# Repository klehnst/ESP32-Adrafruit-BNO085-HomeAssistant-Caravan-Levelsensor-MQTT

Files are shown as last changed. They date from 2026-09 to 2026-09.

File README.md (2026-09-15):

# WoWa-Level – Wohnwagen/Wohnmobil Neigungssensor

Präziser DIY-Neigungssensor zum Nivellieren von Wohnwagen und Wohnmobilen, mit interaktiver Web-UI, Echtzeit-Wasserwaage und Home-Assistant-Anbindung inkl. Feinjustierung.

<p align="center">
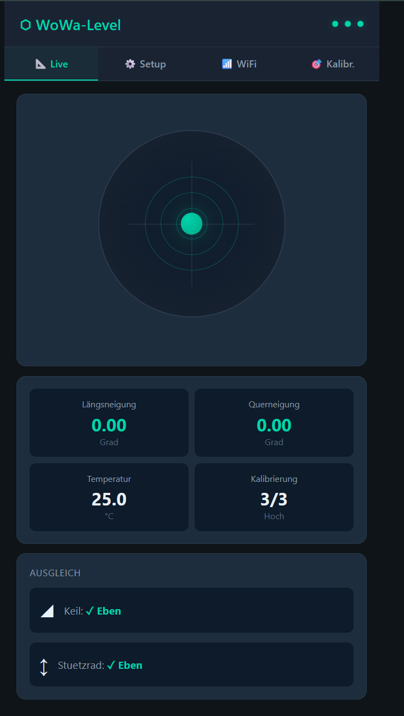
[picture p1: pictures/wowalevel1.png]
Web-UI Hauptseite
  
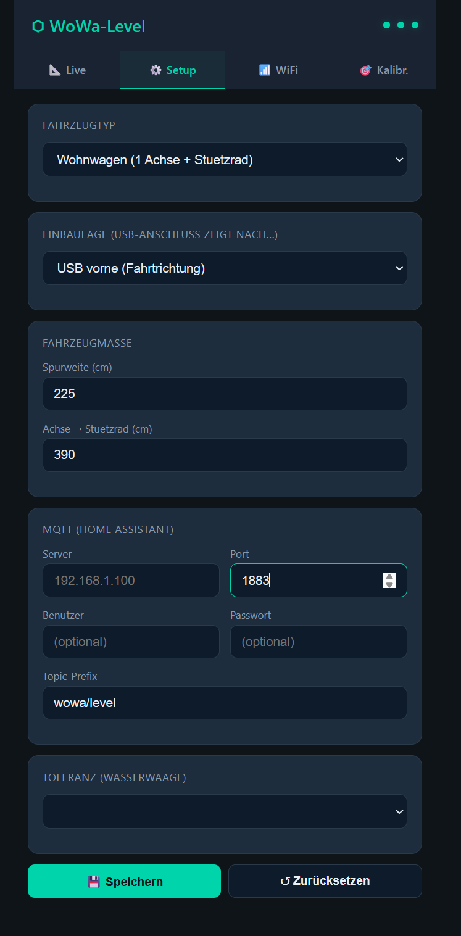
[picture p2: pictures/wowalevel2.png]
Web-UI Einstellungen
  
</p>
<p align="center">
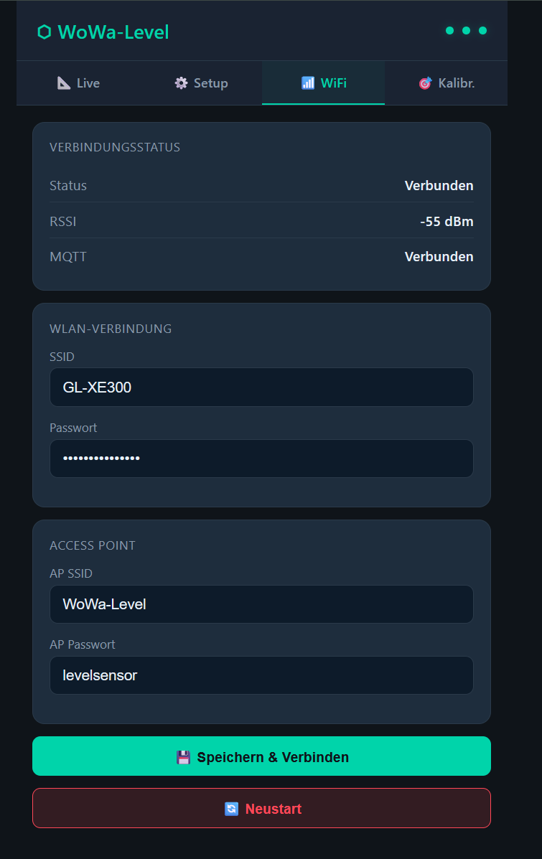
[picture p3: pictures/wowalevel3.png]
Web-UI Kalibrierung
  
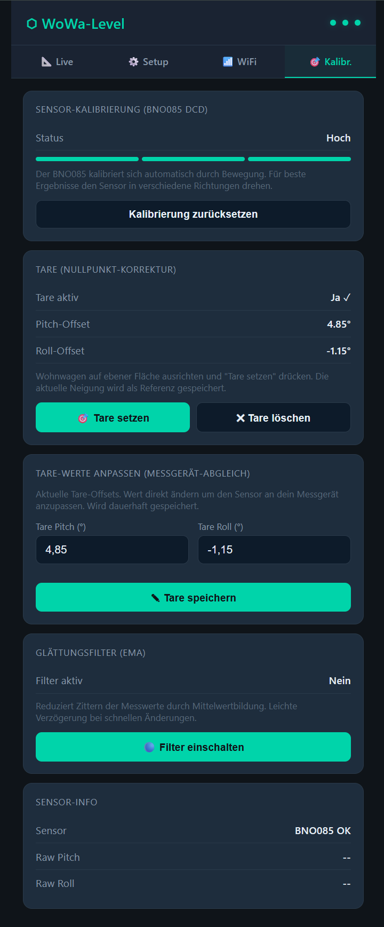
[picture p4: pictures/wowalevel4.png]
Web-UI Live Wasserwaage
  
</p>

---

## Hardware

- **MCU:** ESP32-S3 DevKit
- **IMU:** Adafruit BNO085 9-DoF Breakout (#4754), angebunden über **I2C**
- **Stromversorgung:** USB-C oder 5V/VIN

> **Hinweis:** Das Projekt setzt auf den ESP32-S3. Dieser bietet im Vergleich zu kleineren Controllern eine stabilere Spannungsversorgung unter WiFi-Sende-Peaks und ausreichend Ressourcen für den parallelen Betrieb von WebServer, WebSocket-Streaming und MQTT.

## Pin-Belegung (I2C)

| ESP32-S3 | BNO085 | Funktion |
| --- | --- | --- |
| GPIO1 | SDA | I2C Data |
| GPIO2 | SCL | I2C Clock |
| 3V3 (oder VIN/5V) | VIN | Versorgung |
| GND | GND | Masse |

## 3D-Druck / Gehäuse

Im Ordner [`3D-Print/`](./3D-Print) findest du druckfertige STL-Dateien sowie Vorschaubilder für zwei verschiedene Gehäusevarianten:

- **ESP32-S3 Variante:** `Gehäuse ESP32-S3.stl`, `Deckel ESP32-S3.stl`, `Pfeil ESP32-S3.stl`
- **Standard ESP32-DevKit Variante:** `Gehäuse.stl`, `Deckel.stl`, `Pfeil.stl`

<p align="center">
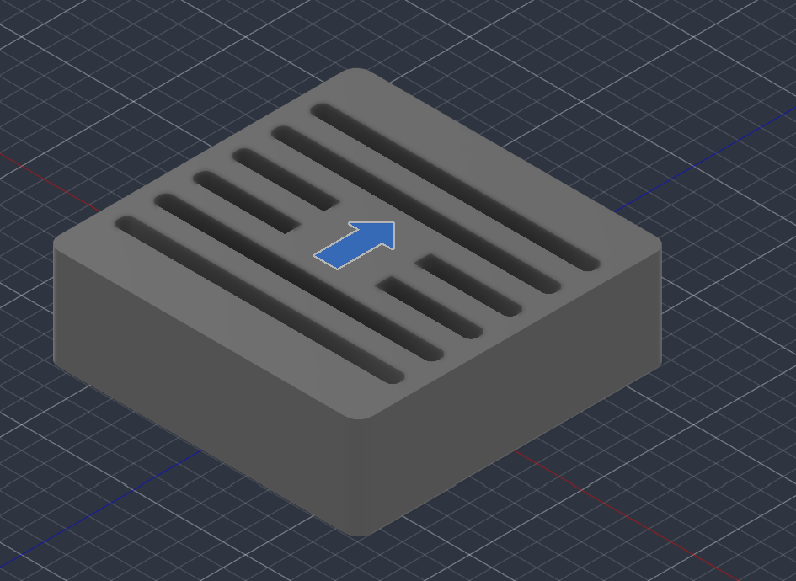
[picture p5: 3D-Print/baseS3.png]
Gehäuse ESP32-S3
  
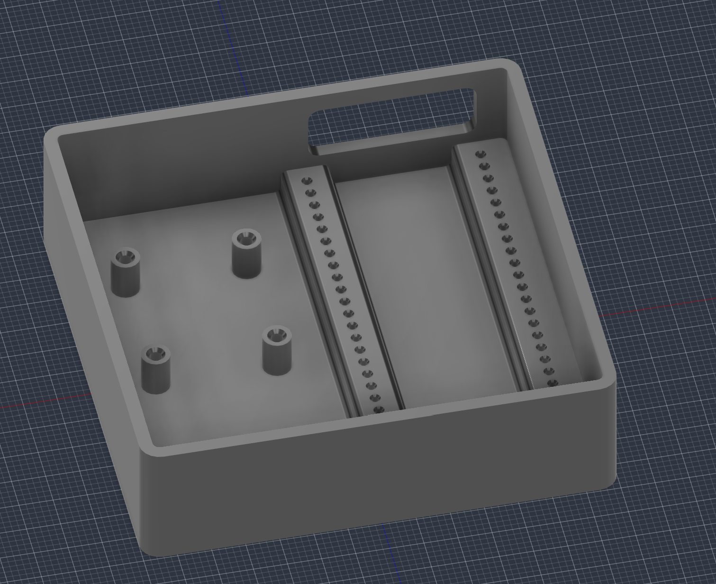
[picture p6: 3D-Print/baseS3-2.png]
Gehäuse ESP32-S3 Ansicht 2
  
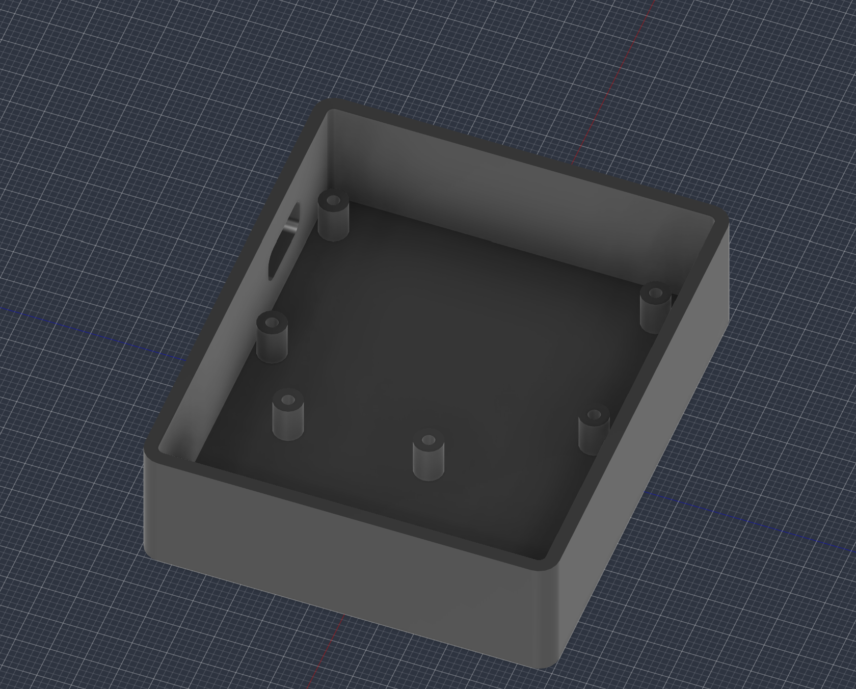
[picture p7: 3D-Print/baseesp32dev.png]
Gehäuse Standard ESP32
  
</p>

## Arduino IDE Setup

### Board

- **Board Manager URL:** `https://raw.githubusercontent.com/espressif/arduino-esp32/gh-pages/package_esp32_index.json`
- **Board:** ESP32S3 Dev Module
- **Flash Size:** 4MB (oder entsprechend dem Modul)
- **Partition Scheme:** Default 4MB with spiffs / LittleFS

### Benötigte Libraries (Library Manager)

1. **SparkFun BNO08x Cortex Based IMU** (by SparkFun)
2. **PubSubClient** (by Nick O'Leary)
3. **ArduinoJson** (by Benoit Blanchon) – Version 7.x
4. **ESPAsyncWebServer** (ESP32Async-Fork)
5. **AsyncTCP** (ESP32Async-Fork)

## Features

- ✅ **BNO085 Accelerometer-Modus:** Driftarm, kein Gyro-Drift, temperaturkompensiert.
- ✅ **Fahrzeugtypen:** Wohnwagen (1 Achse + Stützrad) oder Wohnmobil (2 Achsen, 4 Keile).
- ✅ **Tare-Funktion (Nullpunkt):** Nullpunkt-Kalibrierung mit Speicherung im NVS/Flash.
- ✅ **Tare-Feinjustierung (Fine Offset):** Nachträgliche Korrektur der Pitch- und Roll-Werte (±5.00° in 0.05°-Schritten) über Live-Slider in der Web-UI sowie interaktive `number`-Entitäten in Home Assistant.
- ✅ **Keil-Berechnung:** Errechnet präzise Höhenänderungen in cm für Radkeile und Stützrad (Spurweite / Radstand / Achsabstand konfigurierbar).
- ✅ **Glättungsfilter & Totzone:** Rauschunterdrückung gegen Zittern der Anzeige.
- ✅ **WiFi Manager:** Verlässlicher Connect mit AP-Fallback (`WoWa-Level-AP`) und deaktiviertem WiFi-Power-Save für maximale Stabilität.
- ✅ **MQTT & Home Assistant Auto-Discovery:** Automatische Einbindung aller Sensoren und Bedienelemente inkl. Last-Will-Entdeckung.
- ✅ **Echtzeit Web-UI:** Integrierte responsive Live-Wasserwaage via Websocket, Tabs für Live-Anzeige, Kalibrierung/Feinjustierung und Einstellungen.

## Home Assistant Integration

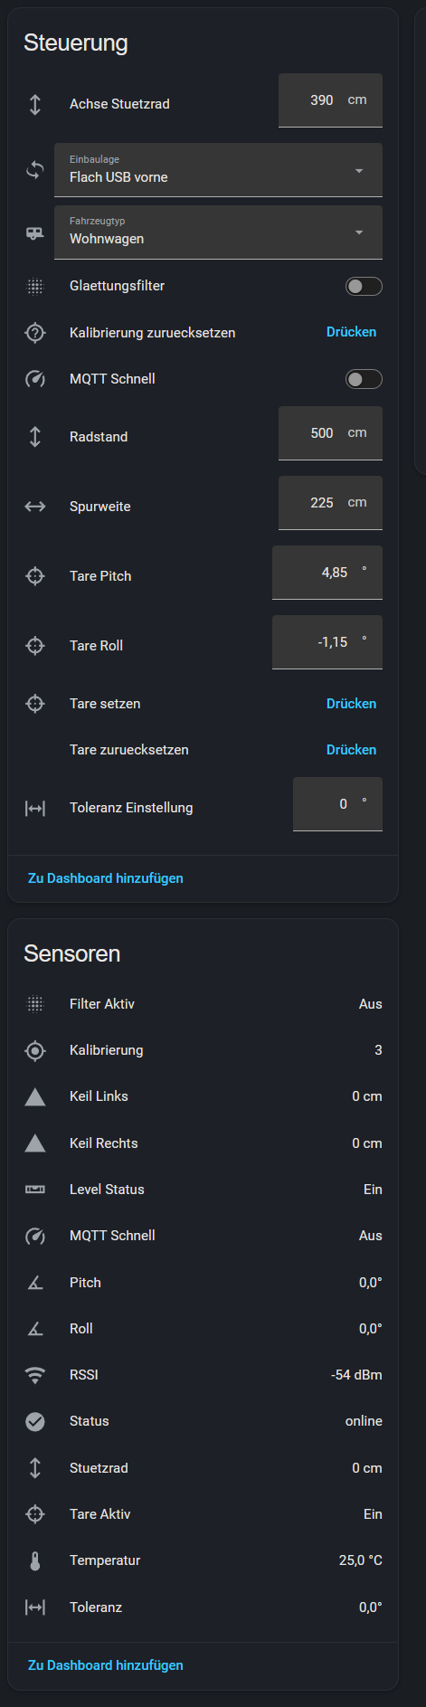
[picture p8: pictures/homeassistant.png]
Home Assistant Dashboard


- **Sensoren:** Pitch, Roll, Keilkorrekturen (Links, Rechts, Stützrad bzw. 4 Keile), Temperatur.
- **Number-Entitäten (Regler):** 
  - `Pitch Feinjustierung` (`-5.0°` bis `+5.0°`, Schrittweite `0.05°`)
  - `Roll Feinjustierung` (`-5.0°` bis `+5.0°`, Schrittweite `0.05°`)
- **Buttons / Switches:** Tare setzen, Tare zurücksetzen, Filter Umschaltung.

> Eine passende Dashboard-Karte befindet sich im Ordner [`WoWa-Level-Card/`](./WoWa-Level-Card).

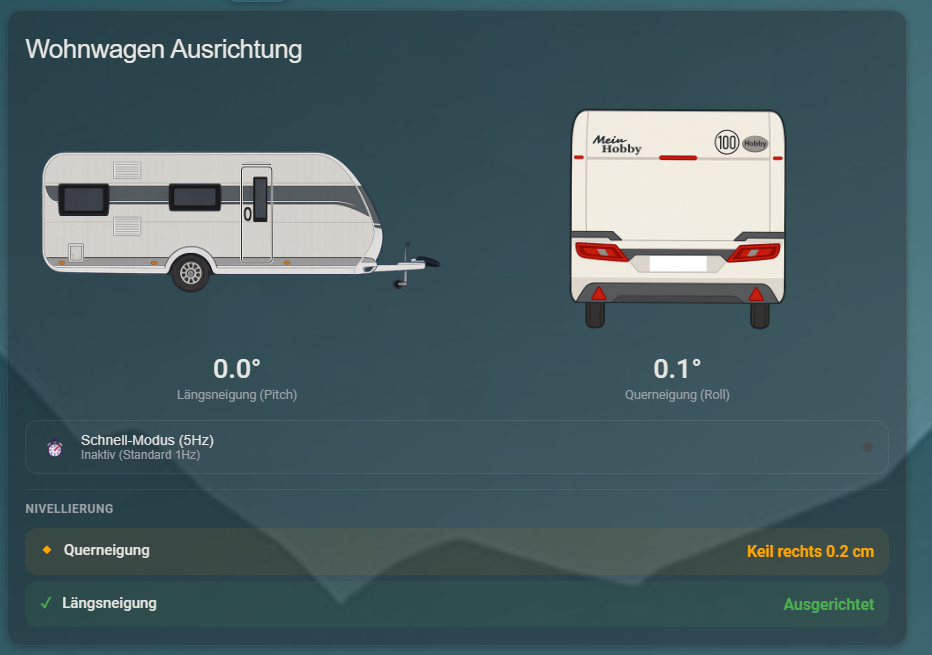
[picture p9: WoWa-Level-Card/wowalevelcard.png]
WoWa Level Card


## MQTT Topics (Prefix: `wowa/level`)

| Topic | Typ | Beschreibung |
| --- | --- | --- |
| `.../pitch` | Sensor | Längsneigung in Grad |
| `.../roll` | Sensor | Querneigung in Grad |
| `.../fine_pitch/state` | State | Aktueller Fine Offset Pitch (Grad) |
| `.../fine_pitch/set` | Command | Fine Offset Pitch setzen (-5.00 bis +5.00) |
| `.../fine_roll/state` | State | Aktueller Fine Offset Roll (Grad) |
| `.../fine_roll/set` | Command | Fine Offset Roll setzen (-5.00 bis +5.00) |
| `.../temperature` | Sensor | Temperatur in °C |
| `.../status` | LWT | `online` / `offline` |
| **Wohnwagen:** | | |
| `.../wedge_left`, `.../wedge_right` | Sensor | Keilhöhe links/rechts (cm) |
| `.../jockey_wheel` | Sensor | Stützrad-Korrektur (cm) |
| **Wohnmobil:** | | |
| `.../wedge_fl`, `.../wedge_fr`, `.../wedge_rl`, `.../wedge_rr` | Sensor | 4 Keile (cm) |

## Erstbenutzung & Kalibrierung

1. **Erstverbindung:** Nach dem ersten Flashen startet der ESP im AP-Modus. Verbinde dich mit dem WLAN `WoWa-Level` (Passwort: `levelsensor`) und öffne `http://192.168.4.1`.
2. **Einbau & Tare:** Richte das Fahrzeug grob aus und drücke in der Web-UI unter **🎯 Kalibr.** den Button **Tare Setzen**.
3. **Feinjustierung:** Überprüfe das Ergebnis mit einer analogen Referenz-Wasserwaage (z. B. auf der Küchenzeile). Gleiche verbleibende Abweichungen komfortabel über die Schieberegler **Pitch Korrektur** und **Roll Korrektur** in der Web-UI oder direkt in Home Assistant ab.
4. **Speichern:** Klicke auf **Feinjustierung Speichern**, um die Offsets dauerhaft im Flash abzulegen.

## Projektstruktur

```text
.
├── 3D-Print/              – STL-Druckdateien und Vorschaubilder (ESP32-S3 & DevKit)
├── data/                  – Dateisystem für LittleFS (enthält index.html)
├── pictures/              – Screenshots für Web-UI und Home Assistant
├── WoWa-Level-Card/       – Lovelace Dashboard Card Ressourcen für Home Assistant
├── config.h               – Systemkonfiguration & Datenstrukturen
├── mqtt_ha.h / .cpp       – MQTT Client & Home Assistant Auto-Discovery
├── sensor.h / .cpp        – BNO085 Ansteuerung, Winkelberechnung & Offsets
├── webserver.h / .cpp     – Webserver, REST-API & WebSocket Broadcast
├── wifi_manager.h / .cpp  – WLAN-Verbindungssteuerung & AP-Fallback
└── wowa_level.ino         – Hauptsketch (Setup & Hauptschleife)

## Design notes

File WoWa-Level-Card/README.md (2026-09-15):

# 🚐 WoWa Level Card v5.3

Eine maßgeschneiderte Lovelace-Karte für **Home Assistant** zur präzisen Ausrichtung und Nivellierung von Wohnwagen und Wohnmobilen.

---

## 🌟 Features

* **Animierte Neigungsanzeige:** Rotations-Visualisierung für Seitenansicht (Längsneigung / Pitch) und Heckansicht (Querneigung / Roll).
* **Nivellier-Anweisungen:**
  * Direkte Höhenanzeige in cm für Keile (links/rechts).
  * Richtungs- und Höhenanweisungen für das Stützrad (hoch/runter in cm).
* **Schnell-Modus / Boost-Modus:**
  * Integrierter Button zum Schalten einer höheren Sensor-Abtastrate (z. B. 5 Hz via ESPHome).
  * Auto-Reset-Timer schaltet den Boost-Modus nach Ablauf der eingestellten Zeit automatisch wieder ab.
* **Erweiterte Konfiguration:**
  * Achsen-Invertierung und Achsen-Tausch (Pitch / Roll).
  * Separates Invertieren der Text-Anweisungen (falls Keilzuordnungen gespiegelt sind).
  * Flacker-Schutz mit Hysterese-Logik an den Toleranzgrenzen.
  * Dauerhafte Textanzeige aller Achsen oder dynamische Aktionsanweisung.
* **Visueller Editor:** Vollständig integrierter GUI-Editor zur bequemen Konfiguration im Dashboard.

WoWa Level Card

---

## 📦 Installation

### Manuelle Installation

1. Erstelle auf deinem Home Assistant Server folgenden Ordner (falls nicht vorhanden):
   ```bash
   /config/www/wowa-level-card/
   ```
2. Speichere die Datei `wowa-level-card.js` in diesem Ordner ab.
3. Lege deine Bilddateien im Unterordner `img` ab:
   ```bash
   /config/www/wowa-level-card/img/seitenansichtkleiner.png
   /config/www/wowa-level-card/img/heckansicht.png
   ```
4. Registriere die Karte als Ressource in Home Assistant:
   * Gehe zu **Einstellungen** ➔ **Dashboards** ➔ oben rechts auf das **3-Punkte-Menü** ➔ **Ressourcen**.
   * Klicke auf **Ressource hinzufügen**.
   * **URL:** `/local/wowa-level-card/wowa-level-card.js?v=5.3`
   * **Typ:** `JavaScript-Modul`

---

## ⚙️ Konfiguration

Die Karte kann direkt über den **visuellen Dashboard-Editor** oder per **YAML** konfiguriert werden.

### YAML-Beispiel

```yaml
type: custom:wowa-level-card
name: Wohnwagen Ausrichtung
entity_roll: sensor.wowa_roll
entity_pitch: sensor.wowa_pitch
entity_level_ok: binary_sensor.wowa_ausgerichtet
entity_wedge_left: sensor.wowa_keil_links
entity_wedge_right: sensor.wowa_keil_rechts
entity_support: sensor.wowa_stutzrad
entity_boost: switch.wowa_sensor_boost
boost_duration: 60
tolerance: 0.5
visual_factor: 3
anti_flicker: true
always_show_text: false
swap_pitch_roll: false
invert_roll: true
invert_pitch: false
invert_roll_text: false
invert_pitch_text: false
image_side: /local/wowa-level-card/img/seitenansichtkleiner.png
image_rear: /local/wowa-level-card/img/heckansicht.png
```

---

## 📋 Optionen

| Parameter | Typ | Standard | Beschreibung |
| :--- | :--- | :--- | :--- |
| `name` | String | `Wohnwagen Ausrichtung` | Titel der Karte im Dashboard |
| `entity_roll` | String | *erforderlich* | Sensor für Querneigung (Roll) in Grad |
| `entity_pitch` | String | *erforderlich* | Sensor für Längsneigung (Pitch) in Grad |
| `entity_level_ok` | String | *optional* | Binary Sensor (`on`/`off`), der die korrekte Ausrichtung meldet |
| `entity_wedge_left` | String | *optional* | Sensor für die Keilhöhe links in cm |
| `entity_wedge_right` | String | *optional* | Sensor für die Keilhöhe rechts in cm |
| `entity_support` | String | *optional* | Sensor für Höhenkorrektur am Stützrad in cm |
| `entity_boost` | String | *optional* | Switch-Entity zur Aktivierung des Fast-Update-Modus |
| `boost_duration` | Zahl | `60` | Auto-Off-Timer für den Boost-Modus in Sekunden |
| `tolerance` | Zahl | `0.5` | Toleranzwert in Grad für die Grün-Bewertung |
| `visual_factor` | Zahl | `3` | Multiplikator für die grafische Neigung |
| `anti_flicker` | Boolean | `true` | Aktiviert die Hysterese gegen Flackern an Grenzwerten |
| `always_show_text` | Boolean | `false` | Zeigt beide Achsen dauerhaft im Textbereich an |
| `swap_pitch_roll` | Boolean | `false` | Vertauscht Pitch- und Roll-Eingänge |
| `invert_roll` | Boolean | `true` | Invertiert die Drehung des Heckbildes |
| `invert_pitch` | Boolean | `false` | Invertiert die Drehung des Seitenbildes |
| `invert_roll_text` | Boolean | `false` | Invertiert Richtungsanweisungen & Keil-Zuordnung links/rechts |
| `invert_pitch_text` | Boolean | `false` | Invertiert Richtungsanweisungen für das Stützrad (hoch/runter) |
| `image_side` | String | `/local/...` | Pfad zum Bild der Seitenansicht |
| `image_rear` | String | `/local/...` | Pfad zum Bild der Heckansicht |

---

## 🖼️ Bild-Assets

Für eine optimale Darstellung sollten die Bilder als **PNG mit transparentem Hintergrund** vorliegen:
* **Seitenansicht (`image_side`):** Seitenprofil des Wohnwagens (Deichsel vorzugsweise nach links).
* **Heckansicht (`image_rear`):** Ansicht des Wohnwagens von hinten.

---

## 📄 Lizenz

MIT License – Frei nutzbar und anpassbar.

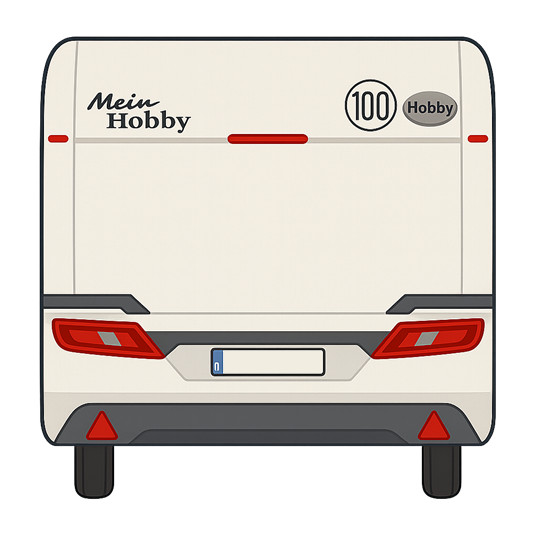
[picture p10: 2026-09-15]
WoWa-Level-Card/heckansicht.png

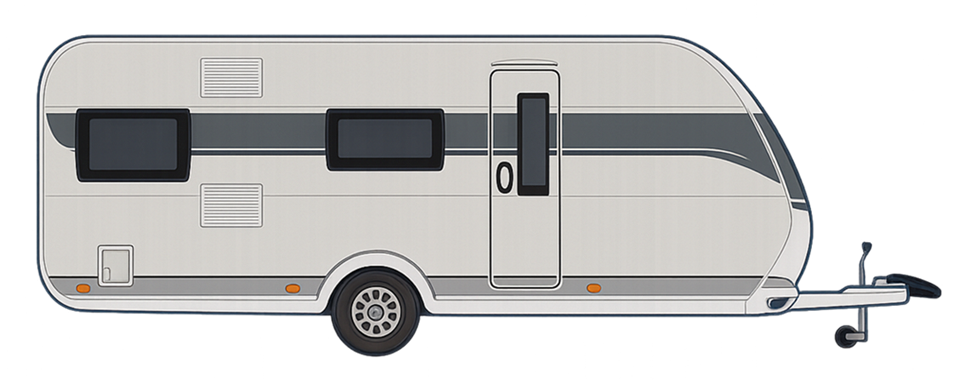
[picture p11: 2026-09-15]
WoWa-Level-Card/seitenansichtkleiner.png

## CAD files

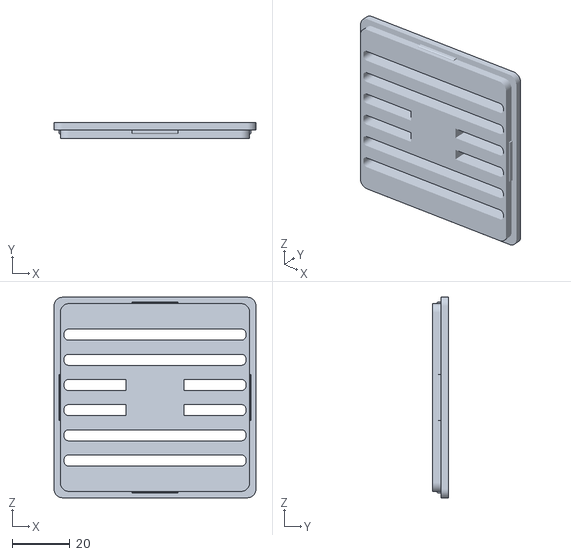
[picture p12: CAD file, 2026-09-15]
3D-Print/Deckel ESP32-S3.stl
70.0 x 5.50 x 69.5

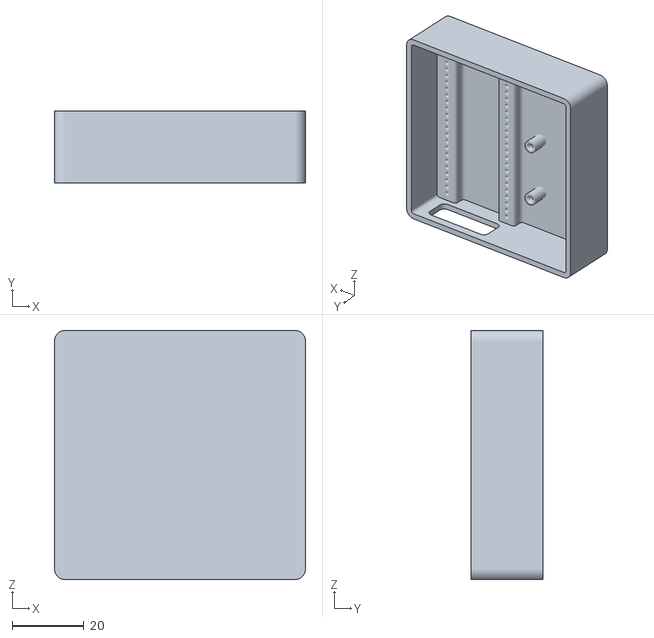
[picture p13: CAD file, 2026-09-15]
3D-Print/Gehäuse ESP32-S3.stl
70.0 x 20.0 x 69.5

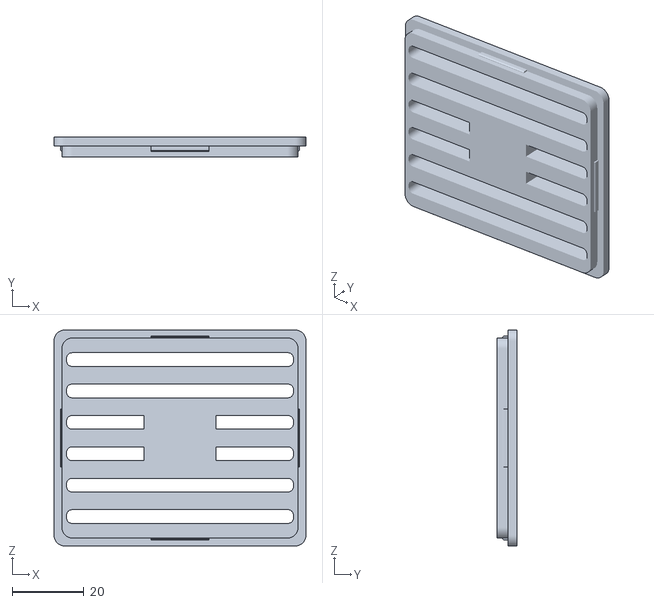
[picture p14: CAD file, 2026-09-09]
3D-Print/Deckel.stl
70.0 x 5.50 x 60.0

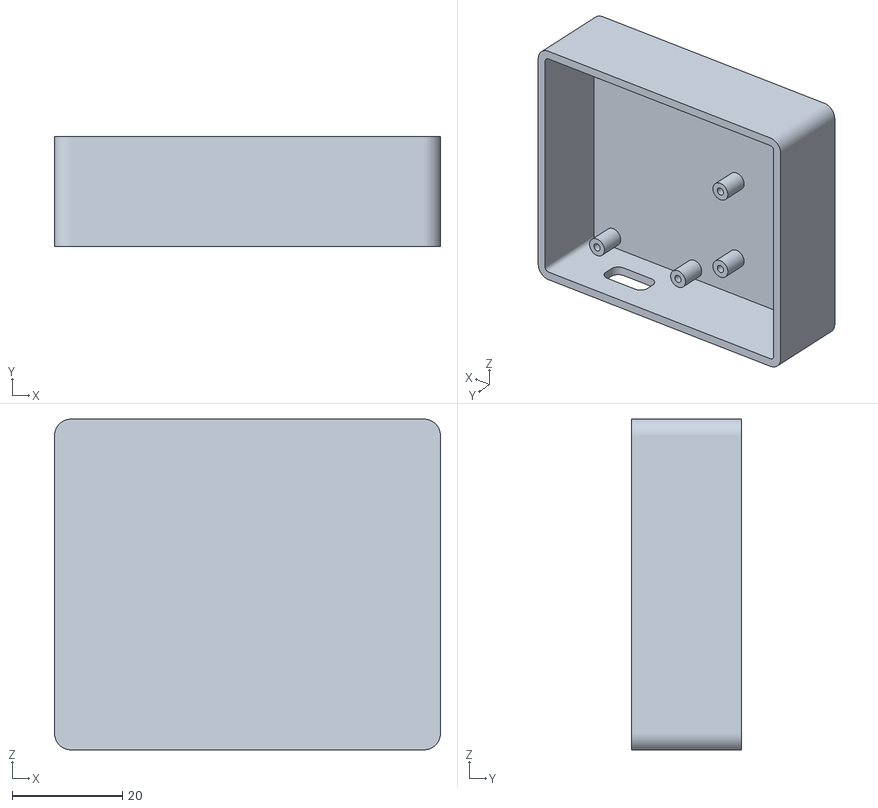
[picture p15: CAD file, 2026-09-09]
3D-Print/Gehäuse.stl
70.0 x 20.0 x 60.0

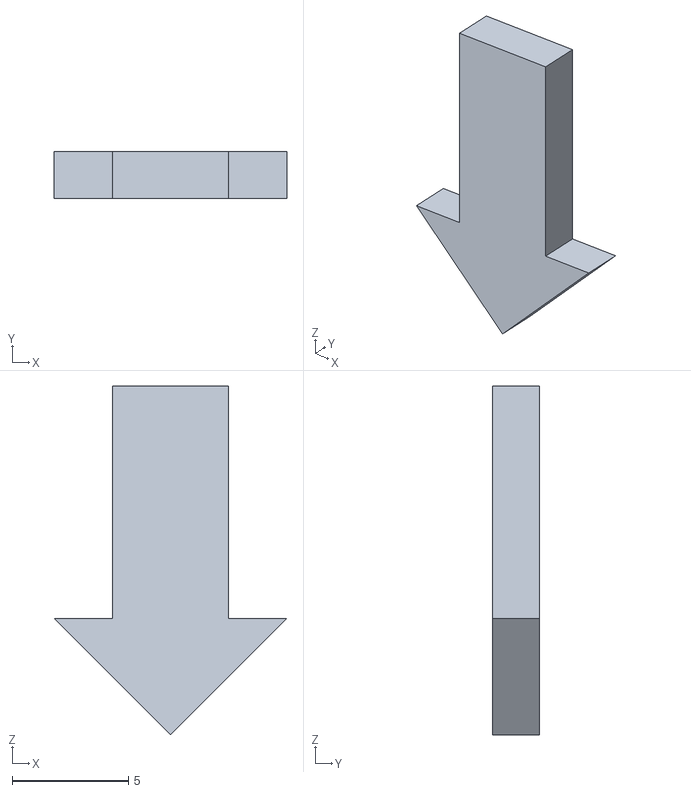
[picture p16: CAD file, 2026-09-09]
3D-Print/Pfeil ESP32-S3.stl
10.0 x 2.00 x 15.0

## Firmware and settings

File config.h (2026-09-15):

#ifndef CONFIG_H
#define CONFIG_H

#include <Arduino.h>

// ============================================================
// PIN DEFINITIONS - ESP32 S3 + BNO085 I2C
#define PIN_I2C_SDA   1
#define PIN_I2C_SCL   2
#define BNO08X_I2C_ADDR 0x4A  // Default I2C address
// ============================================================

// ============================================================
// DEFAULT CONFIGURATION VALUES
// ============================================================
#define DEFAULT_AP_SSID       "WoWa-Level"
#define DEFAULT_AP_PASSWORD   "levelsensor"
#define DEFAULT_AP_IP         "192.168.4.1"
#define WIFI_CONNECT_TIMEOUT  60000  // 60 seconds

#define DEFAULT_MQTT_SERVER   "192.168.1.100"
#define DEFAULT_MQTT_PORT     1883
#define DEFAULT_MQTT_USER     ""
#define DEFAULT_MQTT_PASS     ""
#define DEFAULT_MQTT_PREFIX   "wowa/level"

#define DEFAULT_TRACK_WIDTH   225.0f   // cm - Spurweite
#define DEFAULT_WHEELBASE     500.0f   // cm - Radstand (Wohnmobil)
#define DEFAULT_AXLE_JOCKEY   390.0f   // cm - Achse zu Stuetzrad (Wohnwagen)

#define DEFAULT_TOLERANCE     0.5f     // degrees

#define SENSOR_UPDATE_MS      100      // 10 Hz sensor read
#define MQTT_FAST_MS          200      // 5 Hz (Einrichten)
#define MQTT_SLOW_MS          2000     // 0.5 Hz (Dauerbetrieb)
#define WS_UPDATE_MS          200      // 5 Hz WebSocket

#define CONFIG_FILE           "/config.json"
#define OTA_HOSTNAME          "wowa-level"

// ============================================================
// VEHICLE TYPE
// ============================================================
enum VehicleType {
    VEHICLE_CARAVAN   = 0,  // Wohnwagen (1 Achse + Stuetzrad)
    VEHICLE_MOTORHOME = 1   // Wohnmobil (2 Achsen)
};

// ============================================================
// MOUNTING ORIENTATION
// Flach: Sensor liegt horizontal, USB zeigt in angegebene Richtung
// Wand:  Sensor haengt vertikal an der Wand, USB zeigt nach UNTEN
//        "Wand vorne" = an der Vorderwand montiert
// ============================================================
enum MountOrientation {
    // Flachmontage
    MOUNT_USB_FRONT = 0,   // Flach, USB zeigt nach vorne (Fahrtrichtung)
    MOUNT_USB_BACK  = 1,   // Flach, USB zeigt nach hinten
    MOUNT_USB_LEFT  = 2,   // Flach, USB zeigt nach links
    MOUNT_USB_RIGHT = 3,   // Flach, USB zeigt nach rechts
    // Wandmontage (USB zeigt nach unten)
    MOUNT_WALL_FRONT = 4,  // An Vorderwand (Platine zeigt nach hinten)
    MOUNT_WALL_BACK  = 5,  // An Rueckwand (Platine zeigt nach vorne)
    MOUNT_WALL_LEFT  = 6,  // An linker Wand (Platine zeigt nach rechts)
    MOUNT_WALL_RIGHT = 7   // An rechter Wand (Platine zeigt nach links)
};

// ============================================================
// CONFIGURATION STRUCT
// ============================================================
struct AppConfig {
    // WiFi Station
    char wifi_ssid[64];
    char wifi_pass[64];
    
    // WiFi AP
    char ap_ssid[32];
    char ap_pass[32];
    
    // MQTT
    char mqtt_server[64];
    uint16_t mqtt_port;
    char mqtt_user[32];
    char mqtt_pass[32];
    char mqtt_prefix[32];
    
    // Sensor / Vehicle
    VehicleType vehicle_type;
    MountOrientation mount;
    float track_width;     // Spurweite in cm
    float wheelbase;       // Radstand in cm (Wohnmobil)
    float axle_to_jockey;  // Achse zu Stuetzrad (Wohnwagen) in cm
    float tolerance;       // Toleranz in Grad
    
    // Tare offsets
    float tare_pitch;
    float tare_roll;
    bool tare_active;
    bool filter_active;    // Glaettungsfilter ein/aus
    bool mqtt_fast;        // true=5Hz, false=0.5Hz
};

// ============================================================
// SENSOR DATA STRUCT
// ============================================================
struct SensorData {
    float raw_pitch;
    float raw_roll;
    float pitch;           // nach Tare und Einbaulage
    float roll;            // nach Tare und Einbaulage
    float temperature;
    float wedge_left;      // Keilhoehe links in cm
    float wedge_right;     // Keilhoehe rechts in cm
    float jockey_wheel;    // Stuetzrad-Korrektur in cm
    // Wohnmobil (motorhome)
    float wedge_fl;        // Keil vorne links
    float wedge_fr;        // Keil vorne rechts
    float wedge_rl;        // Keil hinten links
    float wedge_rr;        // Keil hinten rechts
    // Raw gravity vector (for debugging)
    float gx, gy, gz;
    uint8_t cal_status;    // Kalibrierungsstatus 0-3
    bool is_level;         // true wenn innerhalb Toleranz
    bool sensor_ok;
    int rssi;
};

// ============================================================
// GLOBAL EXTERNS
// ============================================================
extern AppConfig config;
extern SensorData sensorData;

#endif // CONFIG_H

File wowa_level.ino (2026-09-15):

/*
 * WoWa-Level - Wohnwagen Neigungssensor
 * ======================================
 * Hardware: ESP32-C3 Super Mini + Adafruit BNO085 (I2C)
 * 
 * Pin Belegung:
 *   GPIO4  -> SDA (I2C)
 *   GPIO10 -> SCL (I2C)
 */

#include <Arduino.h>
#include <ArduinoOTA.h>
#include <WiFi.h>

#include "config.h"
#include "wifi_manager.h"
#include "sensor.h"
#include "mqtt_ha.h"
#include "webserver.h"

AppConfig config;
SensorData sensorData;

static unsigned long lastStatusPrint = 0;
static bool sensorStarted = false;

void setupOTA() {
    ArduinoOTA.setHostname(OTA_HOSTNAME);
    ArduinoOTA.setPassword("wowa2024");
    
    ArduinoOTA.onStart([]() {
        String type = (ArduinoOTA.getCommand() == U_FLASH) ? "sketch" : "filesystem";
        Serial.println("[OTA] Start updating " + type);
    });
    ArduinoOTA.onEnd([]() {
        Serial.println("\n[OTA] Update complete!");
    });
    ArduinoOTA.onProgress([](unsigned int progress, unsigned int total) {
        Serial.printf("[OTA] Progress: %u%%\r", (progress / (total / 100)));
    });
    ArduinoOTA.onError([](ota_error_t error) {
        Serial.printf("[OTA] Error[%u]\n", error);
    });
    
    ArduinoOTA.begin();
    Serial.println("[OTA] Ready");
}

void setup() {
    Serial.begin(115200);
    delay(1000);
    
    Serial.println();
    Serial.println("========================================");
    Serial.println("  WoWa-Level v1.0 (ESP32-C3 + BNO085)");
    Serial.println("========================================");
    Serial.println();
    
    memset(&sensorData, 0, sizeof(SensorData));
    
    // Phase 1: Config
    webserverInit();
    
    // Phase 2: WiFi (blockierend)
    wifiManagerInit();
    
    // Phase 3: Webserver
    webserverStart();
    
    // Phase 4: OTA + MQTT
    setupOTA();
    mqttInit();
    
    // Phase 5: Sensor wird NICHT hier gestartet!
    // Startet erst im loop() nach 3 Sekunden stabilem Betrieb
    Serial.println("[MAIN] Sensor init deferred to loop()");
    
    Serial.printf("[MAIN] Setup done! Heap: %d\n", ESP.getFreeHeap());
}

void loop() {
    wifiManagerLoop();
    ArduinoOTA.handle();
    
    // Deferred sensor init — erst nach 3s im Loop
    if (!sensorStarted && millis() > 5000) {
        sensorStarted = true;
        Serial.println("[MAIN] Deferred sensor init starting...");
        if (!sensorInit()) {
            Serial.println("[MAIN] WARNING: Sensor init failed");
        } else {
            Serial.println("[MAIN] Sensor OK!");
        }
    }
    
    if (sensorStarted) {
        sensorLoop();
    }
    
    mqttLoop();
    webserverLoop();
    
    // Serial commands
    if (Serial.available()) {
        String cmd = Serial.readStringUntil('\n');
        cmd.trim();
        if (cmd == "cal") {
            Serial.println("[CMD] Calibration reset...");
            sensorResetCalibration();
        } else if (cmd == "tare") {
            Serial.println("[CMD] Tare set");
            sensorSetTare();
        } else if (cmd == "notare") {
            Serial.println("[CMD] Tare reset");
            sensorResetTare();
        } else if (cmd == "grav") {
            Serial.printf("[GRAV] gx=%.3f gy=%.3f gz=%.3f\n",
                sensorData.gx, sensorData.gy, sensorData.gz);
            Serial.printf("[GRAV] Mount=%d → P=%.2f R=%.2f\n",
                (int)config.mount, sensorData.pitch, sensorData.roll);
        } else if (cmd == "filter") {
            config.filter_active = !config.filter_active;
            Serial.printf("[CMD] Filter: %s\n", config.filter_active ? "ON" : "OFF");
        } else if (cmd == "fast") {
            config.mqtt_fast = !config.mqtt_fast;
            Serial.printf("[CMD] MQTT: %s\n", config.mqtt_fast ? "5 Hz" : "0.5 Hz");
        } else if (cmd == "help") {
            Serial.println("[CMD] Commands: cal, tare, notare, grav, filter, fast, help");
        }
    }
    
    if (millis() - lastStatusPrint > 10000) {
        lastStatusPrint = millis();
        Serial.printf("[STATUS] P:%.2f R:%.2f Cal:%d WiFi:%s MQTT:%s Heap:%d\n",
            sensorData.pitch, sensorData.roll, sensorData.cal_status,
            getWiFiStateString().c_str(),
            mqttIsConnected() ? "OK" : "---",
            ESP.getFreeHeap());
    }
    
    delay(5);
    yield();
}

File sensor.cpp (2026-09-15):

#include "sensor.h"
#include <Wire.h>
#include <SparkFun_BNO08x_Arduino_Library.h>
#include "webserver.h"   // fuer saveConfig()

static BNO08x imu;
static unsigned long lastSensorRead = 0;

// Totzone fuer Anzeige
#define DEADBAND 0.1f

// ============================================================
// Einbaulage (Remap der Roh-Euler-Winkel je nach Montage)
// ============================================================
static void applyMountingOrientation(float rawPitch, float rawRoll, float* outPitch, float* outRoll) {
    switch (config.mount) {
        // --- Flach auf dem Boden ---
        case MOUNT_USB_FRONT:
            *outPitch = rawPitch;
            *outRoll  = rawRoll;
            break;
        case MOUNT_USB_BACK:
            *outPitch = -rawPitch;
            *outRoll  = -rawRoll;
            break;
        case MOUNT_USB_LEFT:
            *outPitch = rawRoll;
            *outRoll  = -rawPitch;
            break;
        case MOUNT_USB_RIGHT:
            *outPitch = -rawRoll;
            *outRoll  = rawPitch;
            break;

        // --- Wandmontage ---
        case MOUNT_WALL_FRONT:
            *outPitch = rawRoll;
            *outRoll  = rawPitch;
            break;
        case MOUNT_WALL_BACK:
            *outPitch = -rawRoll;
            *outRoll  = -rawPitch;
            break;
        case MOUNT_WALL_LEFT:
            *outPitch = rawPitch;
            *outRoll  = -rawRoll;
            break;
        case MOUNT_WALL_RIGHT:
            *outPitch = -rawPitch;
            *outRoll  = rawRoll;
            break;

        default:
            *outPitch = rawPitch;
            *outRoll  = rawRoll;
            break;
    }
}

// ============================================================
// Keil-Berechnung
// ============================================================
static void calculateWedges() {
    float rollRad = sensorData.roll * DEG_TO_RAD;
    float pitchRad = sensorData.pitch * DEG_TO_RAD;
    
    if (config.vehicle_type == VEHICLE_CARAVAN) {
        float lateralOffset = tanf(rollRad) * config.track_width / 2.0f;
        if (lateralOffset > 0) {
            sensorData.wedge_right = lateralOffset;
            sensorData.wedge_left = 0.0f;
        } else {
            sensorData.wedge_left = -lateralOffset;
            sensorData.wedge_right = 0.0f;
        }
        sensorData.jockey_wheel = tanf(pitchRad) * config.axle_to_jockey;
        sensorData.wedge_fl = sensorData.wedge_fr = 0.0f;
        sensorData.wedge_rl = sensorData.wedge_rr = 0.0f;
    } else {
        float latOff = tanf(rollRad) * config.track_width / 2.0f;
        float lonOff = tanf(pitchRad) * config.wheelbase / 2.0f;
        sensorData.wedge_fl = fmaxf(0.0f, -latOff - lonOff);
        sensorData.wedge_fr = fmaxf(0.0f,  latOff - lonOff);
        sensorData.wedge_rl = fmaxf(0.0f, -latOff + lonOff);
        sensorData.wedge_rr = fmaxf(0.0f,  latOff + lonOff);
        sensorData.wedge_left = sensorData.wedge_right = 0.0f;
        sensorData.jockey_wheel = 0.0f;
    }
}

// ============================================================
// Sensor Init — Game Rotation Vector (Accel + Gyro Fusion)
// ============================================================
bool sensorInit() {
    Serial.println("[Sensor] Initializing I2C...");
    Wire.begin(PIN_I2C_SDA, PIN_I2C_SCL);
    Serial.printf("[Sensor] Pins: SDA=%d SCL=%d\n", PIN_I2C_SDA, PIN_I2C_SCL);
    Serial.println("[Sensor] Connecting to BNO085...");
    
    delay(200);
    
    if (!imu.begin(BNO08X_I2C_ADDR, Wire)) {
        Serial.println("[Sensor] BNO085 init FAILED!");
        sensorData.sensor_ok = false;
        return false;
    }
    
    Serial.println("[Sensor] BNO085 found!");
    delay(100);
    
    // Game Rotation Vector aktiviert 6-DOF Sensor Fusion (Accel + Gyro).
    // Magnetometer ist VOLLSTÄNDIG deaktiviert -> unempfindlich gegen Stromleitungen/Alu.
    // Gyro filtert Rauschen/Vibrationen -> kein Zappeln der Achsen.
    Serial.println("[Sensor] Enabling Game Rotation Vector...");
    if (imu.enableGameRotationVector(SENSOR_UPDATE_MS)) {
        Serial.println("[Sensor] Game Rotation Vector enabled!");
        sensorData.sensor_ok = true;
        sensorData.cal_status = 3; // Fusions-orientiert
        return true;
    }
    
    Serial.println("[Sensor] Game Rotation Vector FAILED!");
    sensorData.sensor_ok = false;
    return false;
}

// ============================================================
// Sensor Loop
// ============================================================
void sensorLoop() {
    if (millis() - lastSensorRead < SENSOR_UPDATE_MS) {
        yield();
        return;
    }
    lastSensorRead = millis();
    
    if (!sensorData.sensor_ok) return;
    
    if (imu.wasReset()) {
        static unsigned long lastReset = 0;
        static int resetCount = 0;
        
        if (millis() - lastReset < 2000) {
            resetCount++;
            if (resetCount > 3) {
                Serial.println("[Sensor] Too many resets - pausing 5s");
                delay(10);
                lastReset = millis() + 5000;
                resetCount = 0;
                return;
            }
        } else {
            resetCount = 0;
        }
        
        lastReset = millis();
        Serial.println("[Sensor] BNO085 was reset - re-enabling Game Rotation Vector");
        imu.enableGameRotationVector(SENSOR_UPDATE_MS);
        delay(10);
    }
    
    if (imu.getSensorEvent()) {
        if (imu.getSensorEventID() == SENSOR_REPORTID_GAME_ROTATION_VECTOR) {
            
            // 1. Quaternionen direkt vom BNO085 abfragen
            float qr = imu.getQuatReal();
            float qi = imu.getQuatI();
            float qj = imu.getQuatJ();
            float qk = imu.getQuatK();

            // 2. Mathematisch exakte Umrechnung von Quaternion -> Roll & Pitch
            float sinr_cosp = 2.0f * (qr * qi + qj * qk);
            float cosr_cosp = 1.0f - 2.0f * (qi * qi + qj * qj);
            float rawRoll = atan2f(sinr_cosp, cosr_cosp) * RAD_TO_DEG;

            float sinp = 2.0f * (qr * qj - qk * qi);
            float rawPitch;
            if (fabsf(sinp) >= 1.0f)
                rawPitch = copysignf(90.0f, sinp);
            else
                rawPitch = asinf(sinp) * RAD_TO_DEG;

            // 3. Ausrichtung / Einbaulage anwenden
            float orientedPitch, orientedRoll;
            applyMountingOrientation(rawPitch, rawRoll, &orientedPitch, &orientedRoll);

            sensorData.raw_pitch = orientedPitch;
            sensorData.raw_roll  = orientedRoll;
            sensorData.cal_status = 3;

            // 4. Tare (Nullpunkt-Offset) anwenden
            if (config.tare_active) {
                sensorData.pitch = orientedPitch - config.tare_pitch;
                sensorData.roll  = orientedRoll  - config.tare_roll;
            } else {
                sensorData.pitch = orientedPitch;
                sensorData.roll  = orientedRoll;
            }
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

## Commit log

2026-09-09 Update WoWa Level Card und Dateien
    [Deckel.stl, Gehäuse.stl, Pfeil.stl]
2026-09-15 Projektstruktur bereinigt und Dateien ersetzt
